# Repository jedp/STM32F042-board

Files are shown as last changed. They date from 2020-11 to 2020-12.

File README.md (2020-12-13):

## STM32F042 Board

PCB Rendering

Dev board for the
[STM32F042](https://www.st.com/resource/en/datasheet/stm32f042c4.pdf).

### Programming

I'm using the ST-Link on an ST Discovery board to program this.

These ST Header CN2 Pins should be connected to the corresponding pins on this
dev board:

1. Don't connect
2. CLK
3. GND
4. DIO
5. NRST

Leave pin 1 (target 3V3) unconnected. It seems to do no harm, but it won't work
if connected.

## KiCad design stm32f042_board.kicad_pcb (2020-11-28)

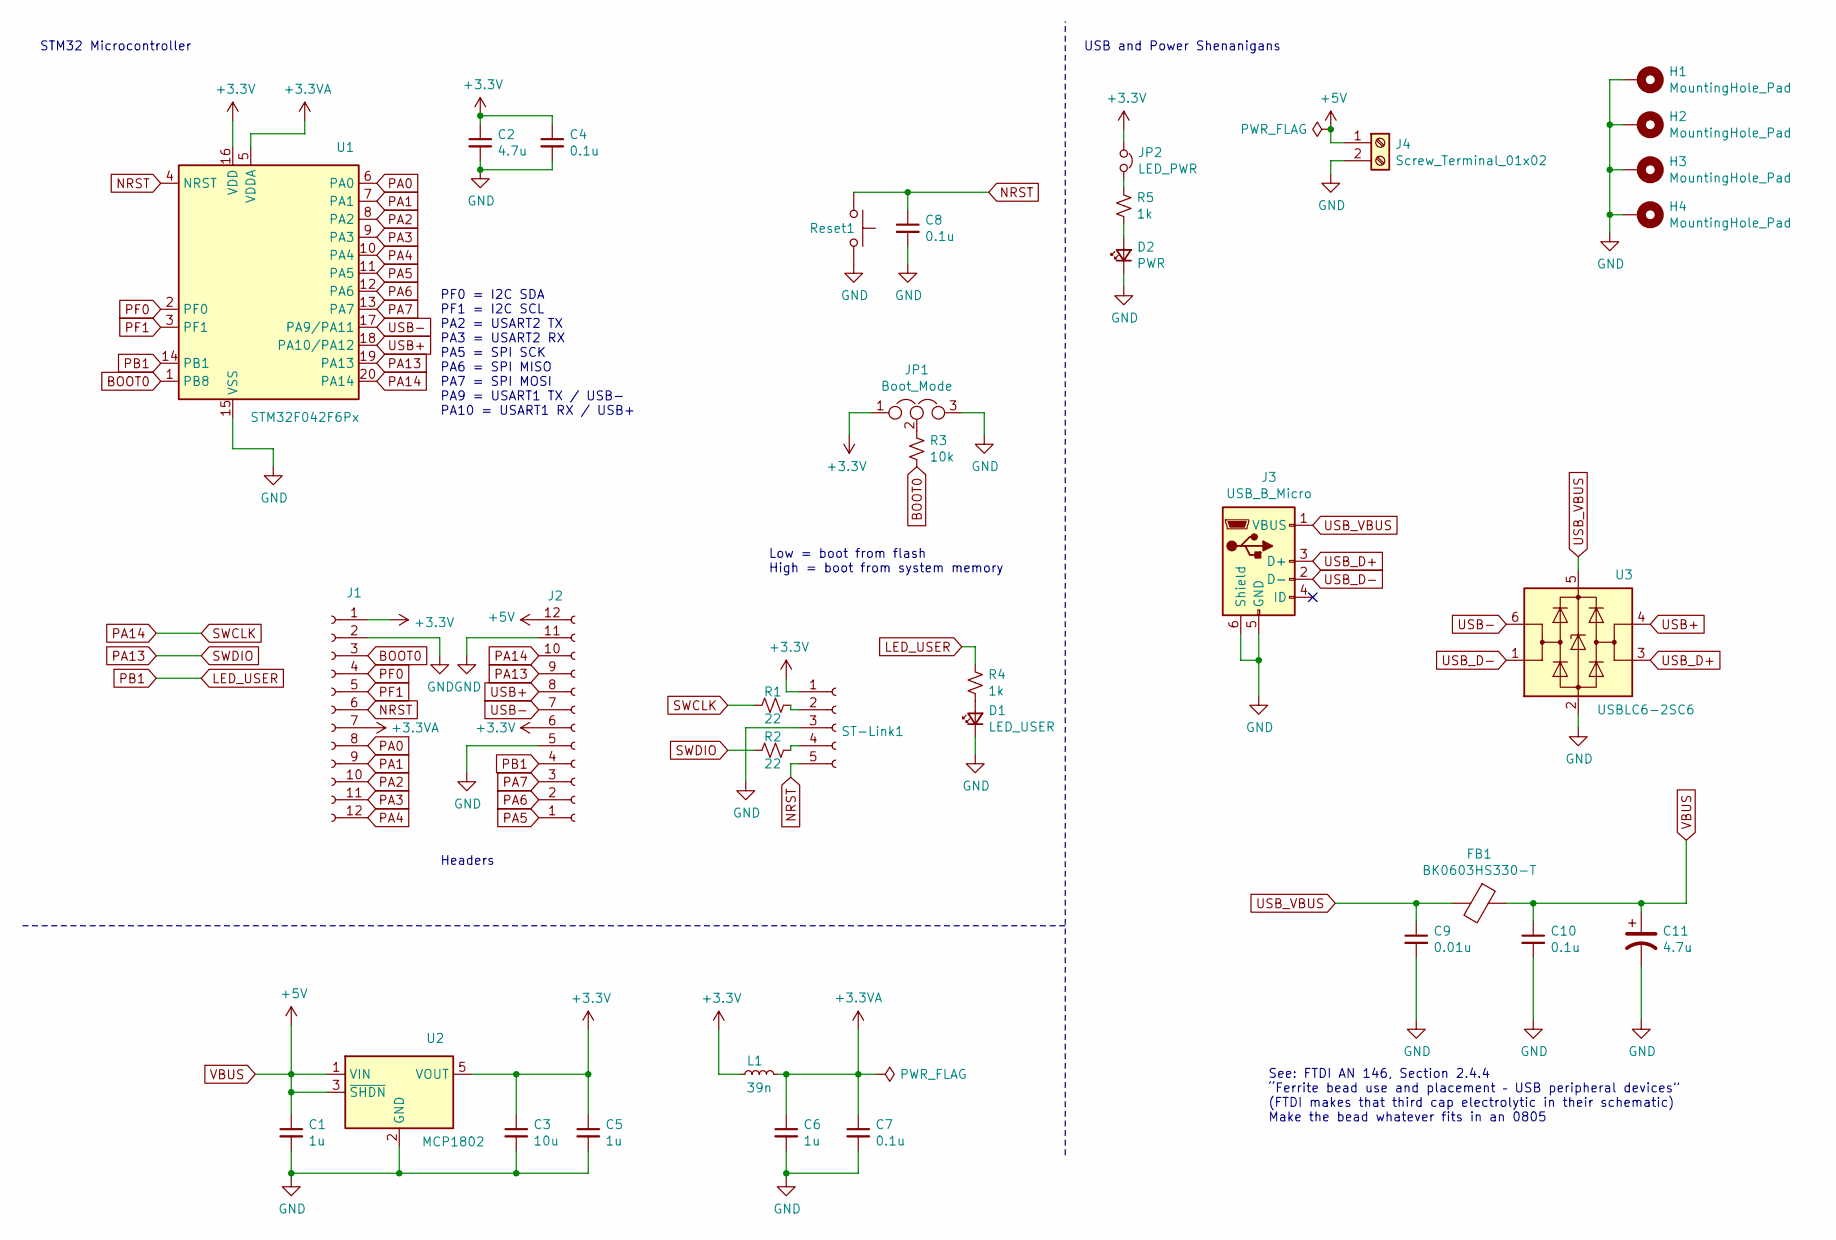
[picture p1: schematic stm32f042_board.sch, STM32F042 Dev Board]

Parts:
C1, C5: 1u; C_0805_2012Metric
C2: 4.7u; C_0603_1608Metric
C3: 10u; C_0805_2012Metric
C4, C7: 0.1u; C_0603_1608Metric
C6: 1u; C_0603_1608Metric
C8, C10: 0.1u; C_0805_2012Metric
C9: 0.01u; C_0805_2012Metric
C11: 4.7u; CP_Elec_4x5.4
D1: LED_USER; LED_0603_1608Metric
D2: PWR; LED_0603_1608Metric
FB1: BK0603HS330-T; L_0805_2012Metric
H1, H2, H3, H4: MountingHole_Pad; MountingHole_3.2mm_M3_ISO7380_Pad
J1, J2: Conn_01x12_Female; PinSocket_1x12_P2.54mm_Vertical
J3: USB_B_Micro; USB_Micro-B_Molex-105017-0001
J4: Screw_Terminal_01x02; TerminalBlock_MetzConnect_Type055_RT01502HDWU_1x02_P5.00mm_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
JP1: Boot_Mode; PinHeader_1x03_P2.54mm_Vertical
JP2: LED_PWR; PinHeader_1x02_P2.54mm_Vertical
L1: 39n; L_0805_2012Metric
R1, R2: 22; R_0805_2012Metric
R3: 10k; R_0603_1608Metric
R4, R5: 1k; R_0805_2012Metric
Reset1: SW_Push; SW_SPST_B3U-1000P-B
ST-Link1: Conn_01x05_Female; PinHeader_1x05_P2.54mm_Vertical
U1: STM32F042F6Px; TSSOP-20_4.4x6.5mm_P0.65mm
U2: MCP1802; SOT-23-5
U3: USBLC6-2SC6; SOT-23-6

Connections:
+3.3VA: C6.1, C7.1, J1.7, L1.2, U1.5 (VDDA)
+3V3: C2.1, C3.1, C4.1, C5.1, J1.1, J2.6, JP1.1, JP2.1, L1.1, ST-Link1.1, U1.16 (VDD), U2.5 (VOUT); also elsewhere on the board
BOOT0: J1.3, R3.2, U1.1 (PB8)
GND: C1.2, C2.2, C3.2, C4.2, C5.2, C6.2, C7.2, C8.2, C9.2, C10.2, C11.2, D1.1 (K), D2.1 (K), H1.1, H2.1, H3.1, H4.1, J1.2, J2.5, J2.11, J3.5 (GND), J3.6 (Shield), J4.2, JP1.3, Reset1.2, ST-Link1.3, U1.15 (VSS), U2.2 (GND), U3.2 (GND); also elsewhere on the board
LED_USER: J2.4, R4.1, U1.14 (PB1)
NRST: C8.1, J1.6, Reset1.1, ST-Link1.5, U1.4 (NRST); also elsewhere on the board
unnamed 6: D1.2 (A), R4.2; also elsewhere on the board
unnamed: D2.2 (A), R5.2
unnamed: JP1.2, R3.1
unnamed: JP2.2, R5.1
unnamed 11: R1.1, ST-Link1.2; also elsewhere on the board
unnamed 12: R2.1, ST-Link1.4; also elsewhere on the board
PA0: J1.8, U1.6 (PA0)
PA1: J1.9, U1.7 (PA1)
PA2: J1.10, U1.8 (PA2)
PA3: J1.11, U1.9 (PA3)
PA4: J1.12, U1.10 (PA4)
PA5: J2.1, U1.11 (PA5)
PA6: J2.2, U1.12 (PA6)
PA7: J2.3, U1.13 (PA7)
PA13: J2.9, R2.2, U1.19 (PA13)
PA14: J2.10, R1.2, U1.20 (PA14)
PF0: J1.4, U1.2 (PF0)
PF1: J1.5, U1.3 (PF1)
USB+: J2.8, U1.18 (PA10/PA12), U3.4 (I/O2)
USB-: J2.7, U1.17 (PA9/PA11), U3.6 (I/O1)
USB_D+: J3.3 (D+), U3.3 (I/O2)
USB_D-: J3.2 (D-), U3.1 (I/O1)
USB_VBUS: C9.1, FB1.2, J3.1 (VBUS), U3.5 (VBUS)
VBUS: C1.1, C10.1, C11.1, FB1.1, J2.12, J4.1, U2.1 (VIN), U2.3 (~SHDN)

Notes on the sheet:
Low = boot from flash High = boot from system memory
See: FTDI AN 146, Section 2.4.4 “Ferrite bead use and placement – USB peripheral devices” (FTDI makes that third cap electrolytic in their schematic) Make the bead whatever fits in an 0805
STM32 Microcontroller
Headers
PF0 = I2C SDA PF1 = I2C SCL PA2 = USART2 TX PA3 = USART2 RX PA5 = SPI SCK PA6 = SPI MISO PA7 = SPI MOSI PA9 = USART1 TX / USB- PA10 = USART1 RX / USB+
USB and Power Shenanigans

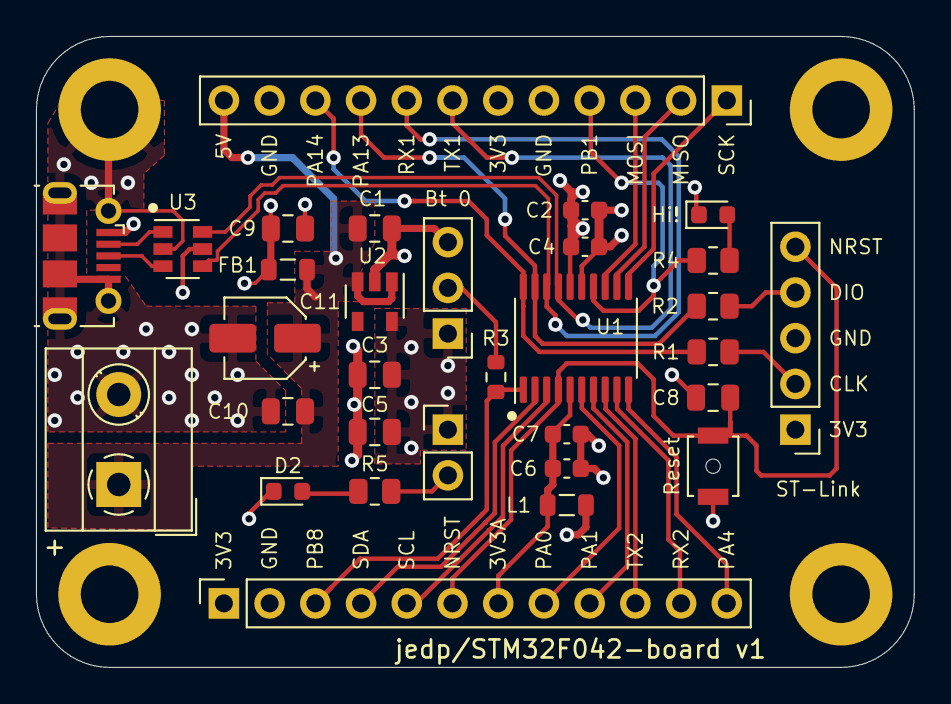
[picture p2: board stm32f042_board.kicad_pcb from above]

Board: 4 copper layers, 48.8 x 35.1 mm, 35 parts (0 on the bottom side), 30 nets.

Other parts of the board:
Hi!: LED_USER; LED_0603_1608Metric
ST-Link: Conn_01x05_Female; PinHeader_1x05_P2.54mm_Vertical

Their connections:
+3V3: ST-Link.1; also elsewhere on the board
GND: Hi!.1, ST-Link.3; also elsewhere on the board
NRST: ST-Link.5; also elsewhere on the board
unnamed 6: Hi!.2; also elsewhere on the board
unnamed 11: ST-Link.2; also elsewhere on the board
unnamed 12: ST-Link.4; also elsewhere on the board
